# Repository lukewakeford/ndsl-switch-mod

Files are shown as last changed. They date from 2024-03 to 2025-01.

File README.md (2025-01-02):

[Instructions for older board versions are available at the relevant tag](https://github.com/lukewakeford/ndsl-switch-mod/tags)

[Buy a kit on my website](https://www.lukewakeford.co.uk) or [Follow me on instagram for updates](https://instagram.com/applecorexy)

# Big thanks to PCBWay!
Many thanks to PCBWay for sponsoring the prototyping of my PCB project. Their support made it possible to bring this design from concept to reality, and their fast, reliable service ensured a smooth and professional process. For PCB manufacturing, prototyping, and much more, check out [PCBWay!](https://pcbway.com/g/ogcF03)

# DSL Switch Mod v3.0
A screen switch breakout board for the DS Lite / GB Macro - requires the TV Out Firmware Mod by [LostNintendoHistory Lost-NDS-TV](https://github.com/LostNintendoHistory/Lost-NDS-TV/tree/main/fwpatch)

Top of v3.0 breakout board
Bottom of v3.0 breakout board
gif demo
Flex cable routing

# If ordering your own boards
- The components used should be available in the BOM.csv file.
- I ordered boards with the bottom half populated from jlcpcb using the gerber, bom and, pick and place files, then soldered on the switches myself.
- The flex cable I use is a 25 pin 0.3mm pitch 120mm long ffc which i sourced from aliexpress

# To use this mod
You need to flash your ds lite with the tv out firmware mod *or* [buy a kit](https://lukewakeford.co.uk/product/dsl-switch-mod-v3-0) - I recommend following [facelesstech's guide](https://bit.ly/3Nf0MW5) as he has gathered the most relevant information in one place.

# Install Tips
- This mod requires the macro mod, this involves soldering a 330r resistor across LEDA2 and LEDC2 Macro Mod Resistor Location
- After removing the stylus tray, The 3D printed button cap can be put in place from inside of the enclosure.
- Use two of the original stylus tray screws (ones with the slight gold tint) to secure the breakout board on top of the cap. [v1.0 video example](https://www.youtube.com/shorts/EsnwIeIT36A)
- If your buttons are not clicking, back off one or both of the mounting screws a tiny bit to adjust.
- If soldering follow this pin out
PIO
- I found that running wires underneath the ds game card slot is a good route for this.
- If installing using the flex cable it must be plugged in to right hand side of the top screen connector nearest pin 1, as pictured:
Top screen connector flex cable install
- You will need to allow the flex cable to fold somewhere underneath the battery. 
- Due to only using ~half of the top screen port it is possible to missalign the flex cable and the swtiches won't work - if this is the case - try again but ensure the flex cable is as far as it can go in to the port and to the right of the port.

# Sources:
- [facelesstech ds-lite-screen-switching-mod](https://facelesstech.wordpress.com/2021/06/20/ds-lite-screen-switching-mod/)
- [LostNintendoHistory Lost-NDS-TV](https://github.com/LostNintendoHistory/Lost-NDS-TV/tree/main/fwpatch)

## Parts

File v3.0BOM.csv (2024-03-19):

ID | Name | Designator | Footprint | Quantity | Manufacturer Part | Manufacturer | Supplier | Supplier Part | Price
1 | FFC-SMD_F0302-B-25-10G-R | U1 | FFC-SMD_F0302-B-25-10G-R | 1 | F0302-B-25-10G-R | XFCN | LCSC | C1884506 | 0.133
2 | KEY-SMD_1TS003B | U2,S2 | KEY-SMD_1TS003B | 2 | 1TS003BBB-1800-3503B | HYP | LCSC | C319401 | 0.056
3 | SW-SMD_L3.9-W2.9-P4.15-LS5.0 | S1 | SW-SMD_L3.9-W2.9-P4.15-LS5.0 | 1 | GT-TC029B-H025-L1N | G-Switch | LCSC | C843669 | 0.06

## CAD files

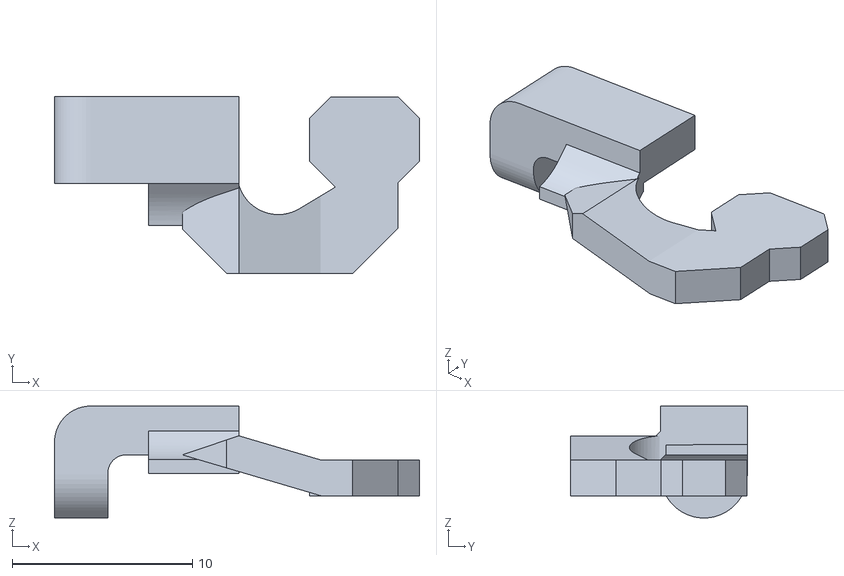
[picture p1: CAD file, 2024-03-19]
v3.0ButtonCap.stl
20.2 x 9.79 x 6.20

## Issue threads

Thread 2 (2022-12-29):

v1.0 board

gtalusan, 2022-12-29:
Hello, apologies for posting on GitHub -- I'm interested in purchasing a button cap and board for your 1.0 variant.  Are you selling this anywhere?  Printing out the PCB isn't a problem for me, but the 3D printer is dark magic for me at the moment.

Thanks!

lukewakeford, 2023-03-08:
@gtalusan Hey sorry for the extremely late reply!
I have been selling a few on eBay, were you able to get hold of one yet?

gtalusan, 2023-03-08:
No worries, I was able to figure it out.  Thanks!

Closed 2023-03-08.

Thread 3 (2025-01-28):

Length of Flex Cable

mrebersv, 2025-01-28:
Thanks for open sourcing this design.  What length of flex cable did you use?  120mm (25p 0.3mm pitch)?

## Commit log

2022-05-25 Adds stl and board files, updates readme
    [BOM_DSL-Switch-Mod_2022-05-25.csv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]
2022-09-07 updates v2 readme
    [BOM_DSL-Switch-Mod_2022-05-25.csv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]
2022-11-08 Updates readme for v2.1 and commits new button cap stl
    [buttonCap.stl, v2.1ButtonCap.stl]
2022-11-18 adds pcb files
    [v2.1BOM.csv, v2.1PickAndPlace.csv]
2024-03-19 Updates to v3.0
    [v2.1BOM.csv, v2.1ButtonCap.stl, v2.1PickAndPlace.csv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]
2025-01-02 Update README.md
    Adds PCBWay thanks
